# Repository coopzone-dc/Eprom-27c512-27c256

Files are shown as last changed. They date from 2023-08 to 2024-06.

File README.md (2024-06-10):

Basic eprom programmer using Arduino Nano.

This is the Arduino scetch needed for an Eprom programmer for 27C256 and 27C512 Eprom chips.
It doesn't need any special PC software for operation.
A terminal software with XMODEM support for uploading the binary is sufficient.
On Linux you can use Minicom and on Windows TeraTerm.
Also `console.py` should work fine.

The onboard CLI looks like this:
```
Started EPROM Programmer V 1.3 12/8/23
  a nnnnn - Set address (for debug)
  r nnnnn mmmmm - show mmmmm bytes at address nnnnn
  i nnnnn mmmmm - show mmmmm bytes at address nnnnn in Intex Hex format
  w nnnnn - write to eprom from binary file using xmodem transfer
  m nnnnn mmmmm - md5sum rom content starting at nnnnn for mmmmmm bytes long
  b nnnnn mmmmm - Check for FF's from nnnnn for mmmmmm bytes long
  h repeat this menu
%
```

This project was put together using bits from other designs. The main aim was just to
get a working programmer for these two chips.

This was used to program Eproms for use with various "Retro" design z80 computers,
mostly based on RC2014 designs.

The circuit has been uploaded. https://github.com/coopzone-dc/Eprom-27c512-27c256/blob/main/Schematic_Eprom_2023-08-19.pdf
I'm going to publish this using EasyEDA as soon as I get time.

https://www.instructables.com/Classic-27c256-27c512-EPROM-Programmer-Using-Nano/

I have also published the EDA design on OSHWLab:

https://oshwlab.com/mycoopzone/eprom_copy

The board required 12.7v supply to program the Eproms.(most are happy between 12.0v and 13.0v), to provide this I use a cheap chinese generic step up supply board
it has a 5v input and the output can be adjusted. the photo shows the board attached to the underside of the pcb.

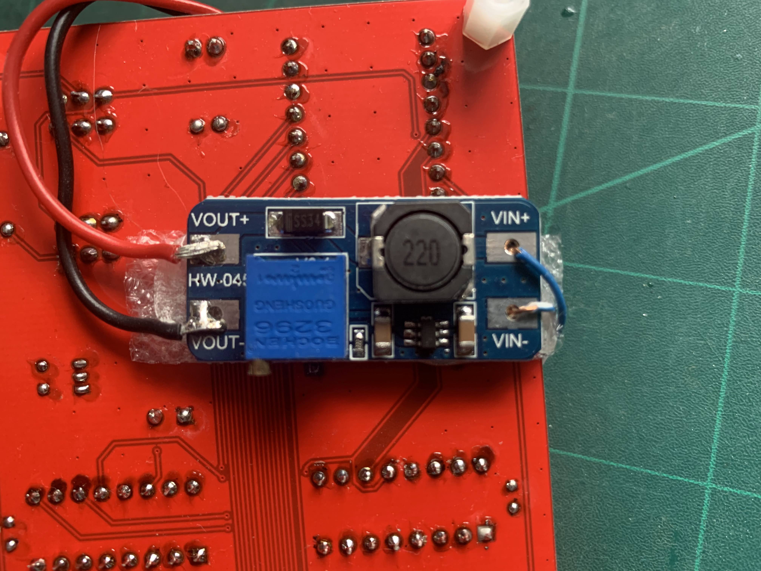
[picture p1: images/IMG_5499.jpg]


Have fun

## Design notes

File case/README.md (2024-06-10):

This is a 3d printed "case" that provides just enough space to house a small step up converter from 5V to the 12.7V required for writing the eprom.

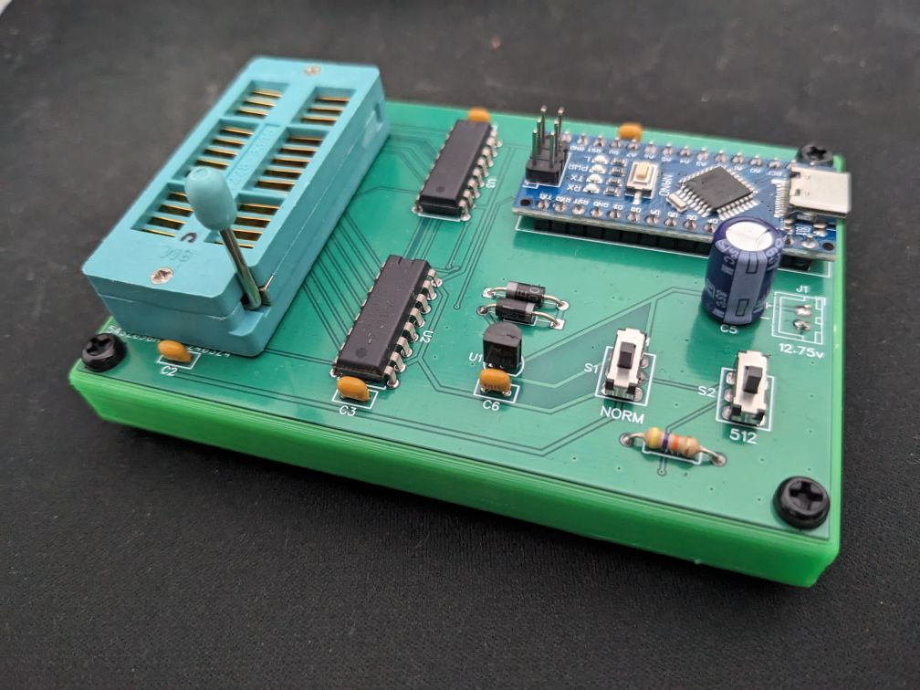
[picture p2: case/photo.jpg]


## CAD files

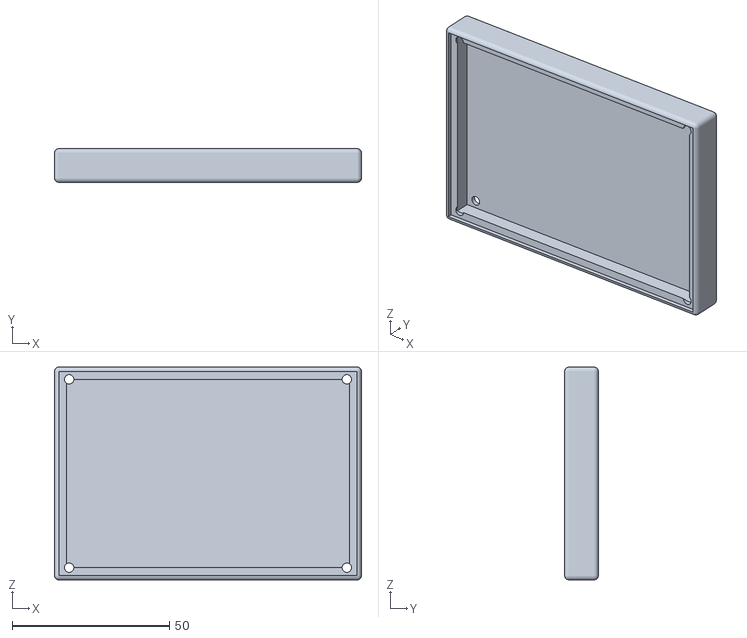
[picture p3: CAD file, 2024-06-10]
case/eprom.stl
97.8 x 10.8 x 67.8

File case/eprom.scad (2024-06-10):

$fn=20;

breite = 95;
tiefe = 8;
hoehe = 65;

schiene = 2.5;
platinendicke = 1.8;


wanddicke = 1.4;
edge_radius = wanddicke;

module schienen() {
    cube([schiene, tiefe, schiene]);

    translate([breite-schiene, 0, 0])
    cube([schiene, tiefe, schiene]);

    translate([0, 0, schiene + platinendicke]) {
        cube([schiene, tiefe, schiene]);
        
        translate([breite-schiene, 0, 0])
        cube([schiene, tiefe, schiene]);
    }
}

schraube=3;

module schr() {
    translate([schraube/2, 20, schraube/2])
    rotate([90, 0, 0])
    cylinder(h=20, d=schraube);
}


module auflage() {
    // pcbauflage
    translate([0, 0, 0])
    linear_extrude(hoehe)
    polygon(points=[[0,0], [0, 2.5], [2.5, 0]]);

    translate([breite, 0, hoehe])
    rotate([0, 180, 0])
    linear_extrude(hoehe)
    polygon(points=[[0,0], [0, 2.5], [2.5, 0]]);

    translate([breite, 0, 0])
    rotate([0, -90, 0])
    linear_extrude(breite)
    polygon(points=[[0,0], [0, 2.5], [2.5, 0]]);

    translate([0, 0, hoehe])
    rotate([0, 90, 0])
    linear_extrude(breite)
    polygon(points=[[0,0], [0, 2.5], [2.5, 0]]);
}

difference() {
    union() {
        difference() {
            hull() {
                sphere(r=edge_radius);
                translate([breite, 0, 0]) sphere(r=edge_radius);
                translate([breite, tiefe, 0]) sphere(r=edge_radius);
                translate([0, tiefe, 0]) sphere(r=edge_radius);
                translate([0, 0, hoehe]) {
                    sphere(r=edge_radius);
                    translate([breite, 0, 0]) sphere(r=edge_radius);
                    translate([breite, tiefe, 0]) sphere(r=edge_radius);
                    translate([0, tiefe, 0]) sphere(r=edge_radius);
                }
            }
            union() {
                translate([0, 0-10, 0]) cube([breite, tiefe+10, hoehe]);
                
            }
        }
        auflage();
    }
    translate([1.8, 0, 1]) schr();
    translate([breite-schraube-1.8, 0, 1]) schr();
    translate([1.8, 0, hoehe-schraube-1]) schr();
    translate([breite-schraube-1.8, 0, hoehe-schraube-1]) schr();
}

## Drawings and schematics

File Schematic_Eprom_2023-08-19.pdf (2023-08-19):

256

## Norm

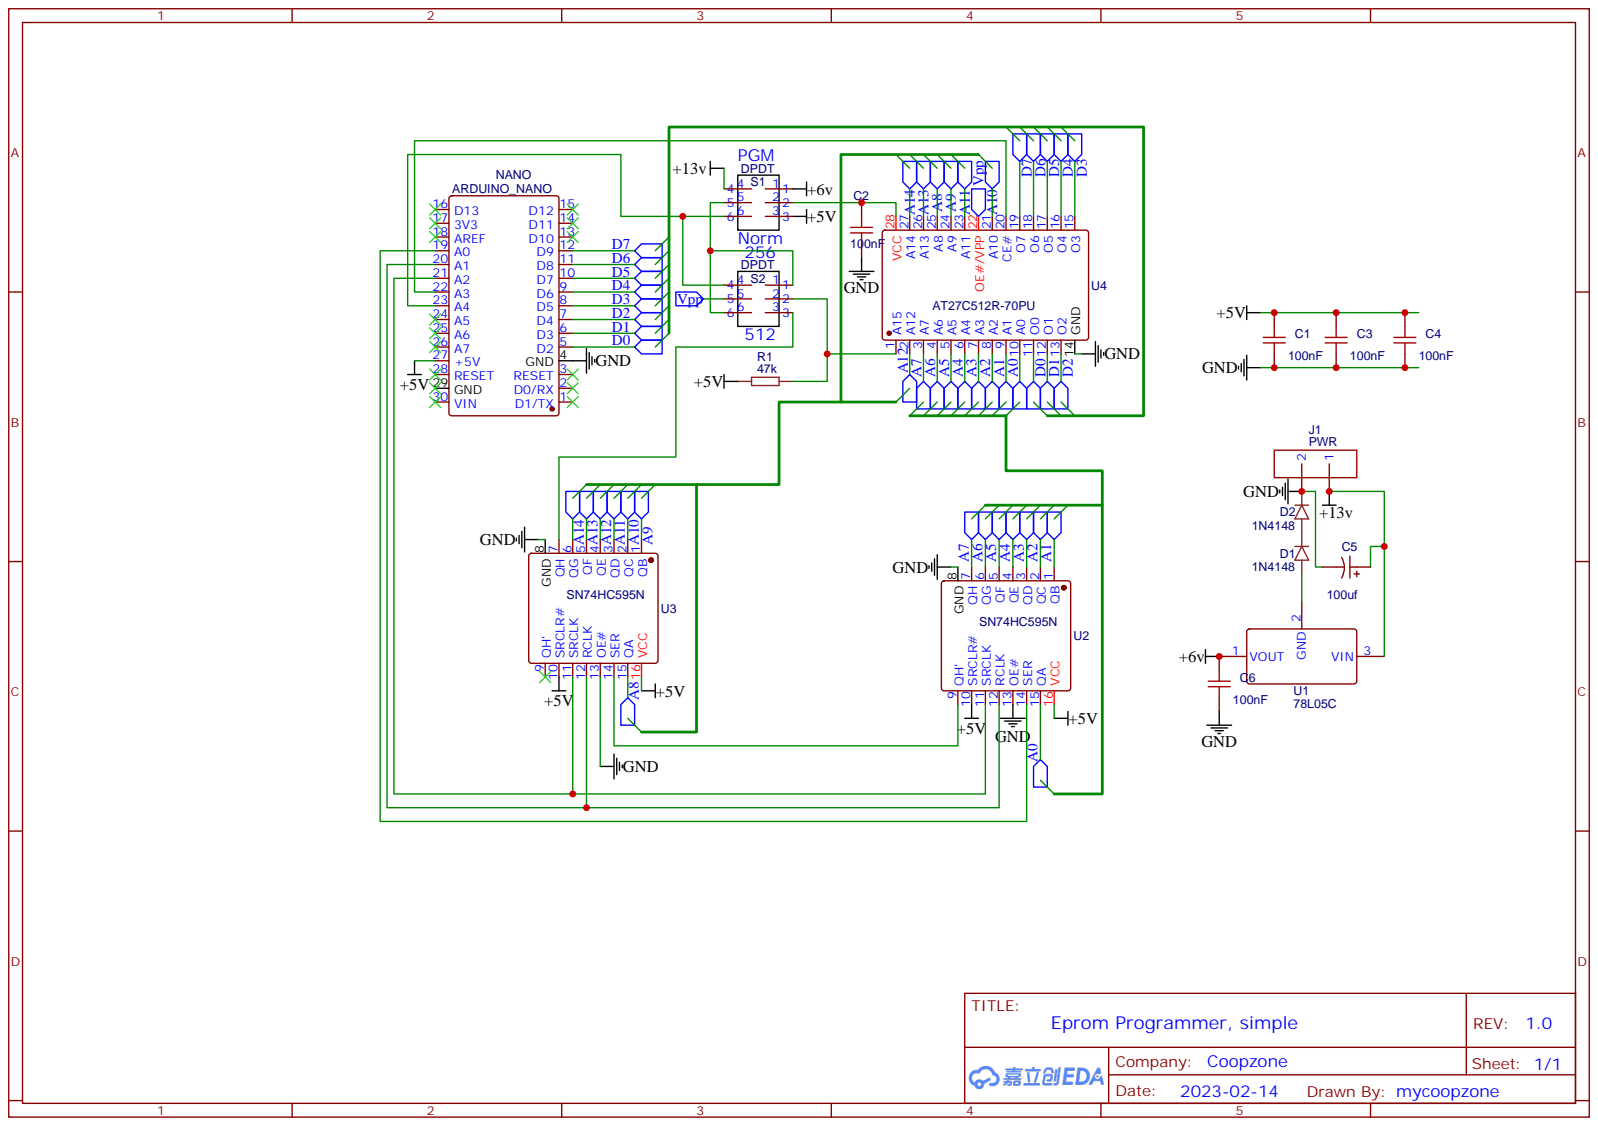
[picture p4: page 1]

GND 14 O3 15 O4 16 O5 17 O6 18 O7 19 CE# 20 A10 21 OE#/VPP 22 A11 23 A9 24 A8 25 A13 26 A14 27 VCC 28

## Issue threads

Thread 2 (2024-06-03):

EDA File

asdil12, 2024-06-03:
Hi, could you add the EDA file for the schematic?

asdil12, 2024-06-07:
Found it: https://oshwlab.com/mycoopzone/eprom_copy
[SCH_Eprom-27c256-27c512_2024-06-08.json](https://github.com/user-attachments/files/15745822/SCH_Eprom-27c256-27c512_2024-06-08.json)

Closed 2024-06-07.

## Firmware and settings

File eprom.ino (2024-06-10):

//coop 18/05/2023 1
//coop 18/05/23 added backspace / delete option
//coop v1.1 7/6/23, removed fast io, not needed. few tweaks to layout etc.
//coop v1.2 10/8/23 added return sequence to make display cleaner
//coop v1.3 12/8/23 added option to read EEprom in intel hex format
#define VERSION "V 1.3 12/8/23"

#include <Arduino.h>
#include <stdio.h>
#include "xmodem.h"
#include "config.h"
#include "md5stuff.h"

// command line
#define ECHO_ON

#define LOWADDRESSLATCH  A0
#define HIGHADDRESSLATCH A1
#define CE      A3
#define OE      A4
#define WE      A5

#define FLASHA16   10
#define FLASHA17   11
#define FLASHA18   12


//4040 stuff
#define COUNTERMASK 0x0fff

#define DS      A0
#define LATCH   A1
#define CLOCK   A2

#define PORTC_DS      0
#define PORTC_LATCH   1
#define PORTC_CLOCK   2

#define PORTC_CE      3
#define PORTC_OE      4
#define PORTC_WE      5


// eeprom stuff
// define the IO lines for the data - bus
#define D0 2
#define D1 3
#define D2 4
#define D3 5
#define D4 6
#define D5 7
#define D6 8
#define D7 9


//command buffer for parsing commands
#define COMMANDSIZE 32
char cmdbuf[COMMANDSIZE];

unsigned long startAddress, endAddress;
unsigned long  lineLength, dataLength;
int loop_cmd = 0; // set to >0 for prompt for command mode
int available;
int bytes;  // Make sure this is not defined in 'loop'!
int total;
unsigned long flashaddress;

//define COMMANDS
#define NOCOMMAND    0
#define SET_ADDRESS  2
#define HELP 3

#define READ_HEX    10
#define IREAD_HEX   11

#define WRITE_BIN   21
#define WRITE_XMODEM 23

#define MD5SUM 40
#define BLANKCHECK 41

/*****************************************************************
 *
 *  CONTROL and DATA functions
 *
 ****************************************************************/

// switch IO lines of databus to INPUT state

void data_bus_input() {
   
  pinMode(D0, INPUT);
  pinMode(D1, INPUT);
  pinMode(D2, INPUT);
  pinMode(D3, INPUT);
  pinMode(D4, INPUT);
  pinMode(D5, INPUT);
  pinMode(D6, INPUT);
  pinMode(D7, INPUT);
}


//switch IO lines of databus to OUTPUT state
void data_bus_output() {
  pinMode(D0, OUTPUT);
  pinMode(D1, OUTPUT);
  pinMode(D2, OUTPUT);
  pinMode(D3, OUTPUT);
  pinMode(D4, OUTPUT);
  pinMode(D5, OUTPUT);
  pinMode(D6, OUTPUT);
  pinMode(D7, OUTPUT);
}

//read a complete byte from the bus
//be sure to set data_bus to input before
byte read_data_bus()
{
  return ((digitalRead(D7) << 7) +
          (digitalRead(D6) << 6) +
          (digitalRead(D5) << 5) +
          (digitalRead(D4) << 4) +
          (digitalRead(D3) << 3) +
          (digitalRead(D2) << 2) +
          (digitalRead(D1) << 1) +
          digitalRead(D0));

}

//write a byte to the data bus
//be sure to set data_bus to output before
void write_data_bus(byte data)
{
  //2 bits belong to PORTB and have to be set separtely
  digitalWrite(D6, (data >> 6) & 0x01);
  digitalWrite(D7, (data >> 7) & 0x01);
  //bit 0 to 6 belong to bit 2 to 8 of PORTD
  // meeprommer used to just OR PIND ... which is wrong. You need to mask too
  PORTD = (PIND & 0x03) | ( data << 2 );
  //digitalWrite(D0, (data & 0x01));
  //digitalWrite(D1, (data >> 1) & 0x01);
  //digitalWrite(D2, (data >> 2) & 0x01);
  //digitalWrite(D3, (data >> 3) & 0x01);
  //digitalWrite(D4, (data >> 4) & 0x01);
  //digitalWrite(D5, (data >> 5) & 0x01);
 }

#ifdef HC595

void set_address_bus(unsigned long address)
{

  //get bits 15 to 8 of address
  byte hi = ((address >>8) & 0xff);
  
  //get bits 7 to 0 of address
  byte low = address & 0xff;

  //disable latch line
  bitClear(PORTC,PORTC_LATCH);

  //shift out highbyte
  fastShiftOut(hi);
  //shift out lowbyte
  fastShiftOut(low);

  //enable latch and set address
  bitSet(PORTC,PORTC_LATCH);

  // Now the top 3 address bits
  digitalWrite(FLASHA16, (address >>16) & 0x01);
  digitalWrite(FLASHA17, (address >>17) & 0x01);
  digitalWrite(FLASHA18, (address >>18) & 0x01);
}

//faster shiftOut function then normal IDE function (about 4 times)
void fastShiftOut(byte data) {
  //clear data pin
  bitClear(PORTC,PORTC_DS);
  //Send each bit of the myDataOut byte MSBFIRST
  for (int i=7; i>=0; i--)  {
    bitClear(PORTC,PORTC_CLOCK);
    //--- Turn data on or off based on value of bit
    if ( bitRead(data,i) == 1) {
      bitSet(PORTC,PORTC_DS);
    }
    else {      
      bitClear(PORTC,PORTC_DS);
    }
    //register shifts bits on upstroke of clock pin  
    bitSet(PORTC,PORTC_CLOCK);
    //zero the data pin after shift to prevent bleed through
    bitClear(PORTC,PORTC_DS);
  }
  //stop shifting
  bitClear(PORTC,PORTC_CLOCK);
}
#endif // HC595



//short function to set the OE(output enable line of the eeprom)
// attention, this line is LOW - active

void set_oe (byte state)
{
  digitalWrite(OE, state);
}

//short function to set the CE(chip enable line of the eeprom)
// attention, this line is LOW - active
void set_ce (byte state)
{
  digitalWrite(CE, state);
}

//short function to set the WE(write enable line of the eeprom)
// attention, this line is LOW - active
void set_we (byte state)
{
  digitalWrite(WE, state);
}

//highlevel function to read a byte from a current address of 4040 and then bump it up one
byte read_next_byte(void)
{
  byte      data = 0;

  //Serial.println("read_next_byte");
  set_address_bus(flashaddress);
  
  //set databus for reading
  data_bus_input();
  //first disable output
  set_oe(HIGH);
  //disable write
  set_we(HIGH);
  //enable chip select
  set_ce(LOW);
  //enable output
  set_oe(LOW);
  delayMicroseconds(1);

  data = read_data_bus();

  //disable output
  set_oe(HIGH);
  set_ce(HIGH);

  flashaddress++;

  return data;

}

byte eprom_write_next_byte(byte b)
{
 
  set_address_bus(flashaddress);

  //first disable output
  set_oe(HIGH);
  //set databus for writing
  data_bus_output();

  //disable write
  //set_we(HIGH);
  write_data_bus(b);
  delayMicroseconds(1); // you are meant to do 2 ... but the function call/exit will consume time
  //enable chip select
  set_ce(LOW);
  //enable output
  //set_oe(LOW);
  delayMicroseconds(98);
  //set_we(HIGH); // latch data
  set_ce(HIGH);
  delayMicroseconds(1);

  data_bus_input();

  flashaddress++;

}

/************************************************
 *
 * COMMAND and PARSING functions
 *
 *************************************************/

//waits for a string submitted via serial connection
//returns only if linebreak is sent or the buffer is filled
void readCommand() {
  //first clear command buffer
  for (int i = 0; i < COMMANDSIZE; i++) cmdbuf[i] = 0;
  //initialize variables
  char c = ' ';
  int idx = 0;
  //now read serial data until linebreak or buffer is full
  while (1) {
    if (idx >= COMMANDSIZE) {
      cmdbuf[idx - 1] = 0;
      break;
    }
    if (Serial.available()) {
      c = Serial.read();
      if ((c == '\n') || (c == '\r')) {
        cmdbuf[idx] = 0;
        break;
      }
      if (( c == 8 ) && (idx > 0)) { //delete backspace, clear on terminal 1 char
        idx--;
        //Serial.print(idx,DEC);
        Serial.write(8);
        Serial.write(' ');
        Serial.write(8);
      }
      if ((c>31) && (c<127)) {
      cmdbuf[idx++] = c;
      Serial.write(c);
      }
      
    }
  }
}

//parse the given command by separating command character and parameters
//at the moment only 5 commands are supported
byte parseCommand() {
  //set ',' to '\0' terminator (command string has a fixed strucure)
  //first string is the command character
  cmdbuf[1]  = 0;
  //second string is startaddress (5 bytes)
  cmdbuf[7]  = 0;
  //third string is a data length (orig file said endaddress (5 bytes))
  cmdbuf[13] = 0;
  //fourth string is length (2 bytes)
  cmdbuf[16] = 0;
  startAddress = hexFiveWord((cmdbuf + 2));
  dataLength = hexFiveWord((cmdbuf + 8));
  lineLength = hexByte(cmdbuf + 14);
  byte retval = 0;
  switch (cmdbuf[0]) {
    case 'a':
      retval = SET_ADDRESS;
      break;
    case 'r':
      retval = READ_HEX;
      break;
    case 'i':
      retval = IREAD_HEX;
      break;
    case 'w':
      retval = WRITE_XMODEM;
      break;
    case 'm':
      retval = MD5SUM;
      break;
    case 'b':
      retval = BLANKCHECK;
      break;
    case 'h':
      retval = HELP;
      break;
    default:
      retval = NOCOMMAND;
      break;
  }

  return retval;
}

/************************************************************
 * convert a single hex digit (0-9,a-f) to byte
 * @param char c single character (digit)
 * @return byte represented by the digit
 ************************************************************/
byte hexDigit(char c)
{
  if (c >= '0' && c <= '9') {
    return c - '0';
  }
  else if (c >= 'a' && c <= 'f') {
    return c - 'a' + 10;
  }
  else if (c >= 'A' && c <= 'F') {
    return c - 'A' + 10;
  }
  else {
    return 0;   // getting here is bad: it means the character was invalid
  }
}

/************************************************************
 * convert a hex byte (00 - ff) to byte
 * @param c-string with the hex value of the byte
 * @return byte represented by the digits
 ************************************************************/
byte hexByte(char* a)
{
  return ((hexDigit(a[0]) * 16) + hexDigit(a[1]));
}

/************************************************************
 * convert a hex word (0000 - ffff) to unsigned int
 * @param c-string with the hex value of the word
 * @return unsigned int represented by the digits
 ************************************************************/
unsigned int hexWord(char* data) {
  if (data[0]==0) {
     return 0;
  }
  return ((hexDigit(data[0]) * 4096) +
          (hexDigit(data[1]) * 256) +
          (hexDigit(data[2]) * 16) +
          (hexDigit(data[3])));
}

// 5 digit hex number
unsigned long hexFiveWord(char* data) {
  if (data[0]==0) {
     return 0;
  }
  return ((hexDigit(data[0])*65536L) +
          (hexDigit(data[1]) * 4096L) +
          (hexDigit(data[2]) * 256L) +
          (hexDigit(data[3]) * 16L) +
          (hexDigit(data[4])));
}
/************************************************
 *
 * INPUT / OUTPUT Functions
 *
 *************************************************/


/**
 * read a data block from eeprom and write out a hex dump
 * of the data to serial connection
 * @param from       start address to read fromm
 * @param to         last address to read from
 * @param linelength how many hex values are written in one line
 **/
void read_block(unsigned long  from, unsigned long  to, int linelength)
{
  flashaddress=from;
  set_address_bus(flashaddress);
  //count the number fo values that are already printed out on the
  //current line
  int        outcount = 0;
  //loop from "from address" to "to address" (included)
  for (unsigned long address = from; address <= to; address++) {
    if (outcount == 0) {
      //print out the address at the beginning of the line
      //Serial.println();
      Serial.print("\r\n");
      Serial.print("0x");
      printAddress(address);
      Serial.print(" : ");
    }
    //print data, separated by a space
    byte data = read_next_byte();
    printByte(data);
    Serial.print(" ");
    outcount = (++outcount % linelength);

  }
  Serial.print("\r\n");
}  


/**
 * read a data block from eeprom and write out a intel hex dump
 * of the data to serial connection
 * @param from       start address to read fromm
 * @param to         last address to read from
 * @param linelength how many hex values are written in one line
 **/
void iread_block(unsigned long  from, unsigned long  to, int linelength)
{
  flashaddress=from;
  set_address_bus(flashaddress);
 
  //count the number fo values that are already printed out on the
  //current line
  int        outcount = 0;
  unsigned int CHK = 0;
  //loop from "from address" to "to address" (included)
  
  for (unsigned long address = from; address <= to; address++) {   
    if (outcount == 0) {
      //print out the start of record 
      Serial.print("\r\n:");
      // set the number of bytes as either 16 or whatever is left until last address
      if ((to - address+1) < linelength) CHK=(to - address+1); else CHK = linelength;    
      printByte(CHK);

      // Print the 4 byte hex address (since address can be 5 digits, it's to big. At this point a fix is needed but this goes upto 64k
      printByte(address / 256);
      printByte(address % 256);
      
      // Add the two address bytes to the checksum value
      CHK += (address / 256);
      CHK += (address % 256);
      Serial.print("00"); //record type 00 always 00 until a fix for bigger eeproms, this goes upto 64k
    }
    
    //print data
    unsigned int data = read_next_byte();
    printByte(data);
    //add into checksum
    CHK += data;
    outcount = (++outcount % linelength);
    //if we are at 16 bytes (linelength) then new line
    if (outcount == 0){
      //Print the checksum for this line
      printByte(((CHK % 256)^255)+1);
      CHK=0;
    }
  }
  // we finished so see if anything left to print, ie the checksum of the last line
  if (outcount != 0) printByte(((CHK % 256)^255)+1);
  //end of hex file record
  Serial.print("\n\r:00000001FF\n\r"); //end of intel hex file
}


void read_md5(unsigned long startAddress, unsigned long dataLength) {
  unsigned long  bytesleft;
  int bytestoprocess;
  int i;
  char md5buffer[64];
  char md5str[33];
  MD5_CTX context;
  unsigned char digest[16];
  
  flashaddress=startAddress;
  set_address_bus(flashaddress);

  md5str[0] = '\0';
  MD5Init(&context);
  
  while (flashaddress < (startAddress + dataLength) ) {
     // Work out how many bytes are left
     bytesleft = ((startAddress + dataLength) - flashaddress);
     bytestoprocess=64;
     if (bytesleft < 64) {
        bytestoprocess = bytesleft;
     }
     for (i=0;i<bytestoprocess;i++) {
        md5buffer[i] = (char) read_next_byte();
     }
     MD5Update(&context, md5buffer, bytestoprocess);
     // No need to bump up flash address as read_next_byte does it.
  }

  MD5Final(digest, &context);

  make_digest(md5str, digest, 16);
  Serial.println(md5str);
  Serial.println();
  
}

void blank_check(unsigned long startAddress, unsigned long dataLength) {
  byte b;
  boolean found_non_ff = false;
    
  flashaddress=startAddress;
  set_address_bus(flashaddress);
  
  while (flashaddress < (startAddress + dataLength) ) {
     b = read_next_byte();
     if (b != 0xff) {
         found_non_ff = true;
         flashaddress--;
         break;
     }
  }   
  if (found_non_ff) {
    Serial.print("\n\rFound byte ");
    printByte(b);
    Serial.print(" at ");
    printAddress(flashaddress);
    Serial.println();
  } else {
    Serial.println("Scan complete. Only FF\'s found");
  }
}

/**
 * print out a 20 bit word as 5 character hex value
 **/
void printAddress(unsigned long address) {
  if (address < 0x0010) Serial.print("0");
  if (address < 0x0100) Serial.print("0");
  if (address < 0x1000) Serial.print("0");
  if (address < 0x10000) Serial.print("0");
  Serial.print(address, HEX);

}

/**
 * print out a byte as 2 character hex value
 **/
void printByte(byte data) {
  if (data < 0x10) Serial.print("0");
  Serial.print(data, HEX);
}

/************************************************
 *
 * MAIN
 *
 *************************************************/
void menu() {
//menu as a constant
static const char MMENU[] PROGMEM ="\n\r"
  "  a nnnnn - Set address (for debug)\n\r"
  "  r nnnnn mmmmm - show mmmmm bytes at address nnnnn\n\r"
  "  i nnnnn mmmmm - show mmmmm bytes at address nnnnn in Intex Hex format\n\r"
  "  w nnnnn - write to eprom from binary file using xmodem transfer\n\r"
  "  m nnnnn mmmmm - md5sum rom content starting at nnnnn for mmmmmm bytes long\n\r"
  "  b nnnnn mmmmm - Check for FF\'s from nnnnn for mmmmmm bytes long\n\r"
  "  h repeat this menu\n\r";
  Serial.print((__FlashStringHelper*)MMENU);
}

void setup() {

#ifdef HC595
  pinMode(DS,OUTPUT);
  pinMode(LATCH,OUTPUT);
  pinMode(CLOCK,OUTPUT);
#endif
  
  pinMode(CE, OUTPUT);
  digitalWrite(CE, HIGH);
  pinMode(WE, OUTPUT);
  digitalWrite(WE, HIGH);

  pinMode(OE, OUTPUT);
  digitalWrite(OE, HIGH);
  
  pinMode(FLASHA16, OUTPUT);
  pinMode(FLASHA17, OUTPUT);
  pinMode(FLASHA18, OUTPUT);

  xmodem_set_config(XMODEM_MODE_ORIGINAL);
  Serial.begin(115200);
  Serial.print("Started EPROM Programmer ");
  Serial.print(VERSION);
  menu();
}

static bool data_handler(const uint8_t* buffer, size_t size)
{
  for(int c=0; c<size; c++) {
    eprom_write_next_byte(buffer[c]);
  }
  return true;
}

static bool input_handler(int c)
{
  return false;
}

/**
 * main loop, that runs invinite times, parsing a given command and
 * executing the given read or write requestes.
 **/
void loop() {
  byte a, b;
  unsigned int c;

static const char MINST1[] PROGMEM = "Switch to PGM on the board, then\n\r"
  "start an xmodem transfer in your terminal ...\n\r";
static const char MINST2[] PROGMEM = "\n\rTransfer finished. switch back to NORM before any other command.\n\r";

    Serial.print("\r% "); // show the prompt
    readCommand();
    Serial.print("\n\r");
    byte cmd = parseCommand();
    //Serial.print("\n\r");
    
    switch (cmd) {

      case HELP:
        menu();
        break;
        
      // setting the address like this is mainly used for testing to see if your 74HC595s or 74LS374s are working.
      case SET_ADDRESS:
        // Set the address bus to an arbitrary value.
        // Useful for debugging shift-register wiring, byte-order.
        // e.g. a,00FF
        Serial.print("Setting address bus to 0x");
        Serial.print(cmdbuf + 2);
        Serial.print(" ");
        Serial.println(startAddress);
        set_address_bus(startAddress);
        break;
  
      case READ_HEX:
        //set a default if needed to prevent infinite loop
        if (lineLength == 0) lineLength = 16;
        if (dataLength == 0) {
           dataLength = 0x80;
        }
        endAddress = startAddress + dataLength - 1;
        read_block(startAddress, endAddress, lineLength);
        break;
     case IREAD_HEX: //intel format
        //set a default if needed to prevent infinite loop
        if (lineLength == 0) lineLength = 16;
        if (dataLength == 0) {
           dataLength = 0x80;
        }
        endAddress = startAddress + dataLength - 1;
        iread_block(startAddress, endAddress, lineLength);
        break;
      case MD5SUM:
        //set a default if needed to prevent infinite loop
        
        if (dataLength == 0) {
           dataLength = 0x80;
        }
        endAddress = startAddress + dataLength - 1;
        Serial.println("Reading md5");
        read_md5(startAddress, dataLength);
        break;
     case BLANKCHECK:
        //set a default if needed to prevent infinite loop
        
        if (dataLength == 0) {
           dataLength = 0x80;
        }
        endAddress = startAddress + dataLength - 1;
        Serial.println("Checking for anything that isn\'t an FF");
        blank_check(startAddress, dataLength);
        break;
                 
      case WRITE_XMODEM:
        bytes = 0;
        total=0;
        flashaddress=startAddress;
        set_address_bus(startAddress);

        Serial.print((__FlashStringHelper*)MINST1);
        int32_t sizeReceived = xmodem_receive(NULL, input_handler, data_handler);

        delay(1000);
        while (Serial.available()) Serial.read();
        Serial.print((__FlashStringHelper*)MINST2);
        printAddress(sizeReceived); Serial.print(" bytes written\n\r");
        break;
        
      default:
        break;
    }
}

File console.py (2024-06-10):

#!/usr/bin/python3

import serial
import sys
import select
import tty
import termios
import time

SOH = b'\x01'
EOT = b'\x04'
ACK = b'\x06'
NAK = b'\x15'
CAN = b'\x18'
SUB = b'\x1A'

def main():
    if len(sys.argv) < 2:
        print(f'Usage: {sys.argv[0]} /dev/ttyUSB0 [default xmodem filename]')
        return
    device = sys.argv[1]
    old_settings = termios.tcgetattr(0)
    with serial.Serial(device, baudrate=115200, timeout=1) as term:
        try:
            default_fn = ''
            default_str = ''
            if len(sys.argv) >= 3:
                default_fn = sys.argv[2]
                default_str = f"\nDefault xmodem filename: '{default_fn}'\nPress return to use it.\n"
            print(f"Connected to {device} - Exit via escape char '^]'")
            tty.setraw(sys.stdin.fileno())
            term.write(b"\n")
            while True:
                readable, _, _ = select.select([term.fileno(), sys.stdin.fileno()], [], [])
                for s in readable:
                    if s == term.fileno():
                        data = term.read(1)
                        if not data:
                            print("Connection closed.")
                            return
                        if data == NAK:
                            termios.tcsetattr(0, termios.TCSADRAIN, old_settings)
                            fn = input(f"\nXMODEM requested. {default_str}Filename?\n> ") or default_fn
                            tty.setraw(sys.stdin.fileno())
                            try:
                                xmodem_tx(term, fn)
                            except Exception as e:
                                print(e)
                                pass
                        print(data.decode('ascii', errors='ignore'), end='', flush=True)
                    elif s == sys.stdin.fileno():
                        char = sys.stdin.buffer.read(1)
                        if char == b'\x1d':
                            print("Exiting.")
                            return
                        term.write(char)
        finally:
            termios.tcsetattr(0, termios.TCSADRAIN, old_settings)

def checksum(data):
    return sum(data) % 256

def xmodem_tx(term, fn):
    with open(fn, 'rb') as f:
        def send_packet(packet_number, payload):
            packet = bytearray()
            packet.append(SOH[0])
            packet.append(packet_number & 0xFF)
            packet.append(0xFF - (packet_number & 0xFF))
            packet.extend(payload)
            packet.append(checksum(payload))
            term.write(packet)

        packet_number = 1
        last_packet = False
        term.read_all() # flush NAK XMODEM req from buffer
        while not last_packet:
            payload = bytearray(f.read(128))
            if len(payload) < 128:
                payload.extend(bytearray(SUB) * (128 - len(payload)))
                last_packet = True
            send_packet(packet_number, payload)

            while True:
                response = term.read(1)
                if response == ACK:
                    packet_number += 1
                    print('.', end='', flush=True)
                    break
                elif response == NAK:
                    send_packet(packet_number, payload)
                elif response == CAN:
                    print("Error: Remote canceled XMODEM transfer")
                    return False
                elif response == b'':
                    pass
                else:
                    time.sleep(1)

        term.write(EOT)
        while term.read(1) != ACK:
            term.write(EOT)
        return True

if __name__ == '__main__':
    main()

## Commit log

2023-06-07 Gerba files for PCB
    This is the PCB board for use with this software
2023-08-19 Add files via upload
    Circuit diagram
2024-06-04 Update README.md added info about 12.7v supply
2024-06-07 Improve readme and tell user what the device does.
2024-06-10 Add case
    [eprom.scad, eprom.stl]
